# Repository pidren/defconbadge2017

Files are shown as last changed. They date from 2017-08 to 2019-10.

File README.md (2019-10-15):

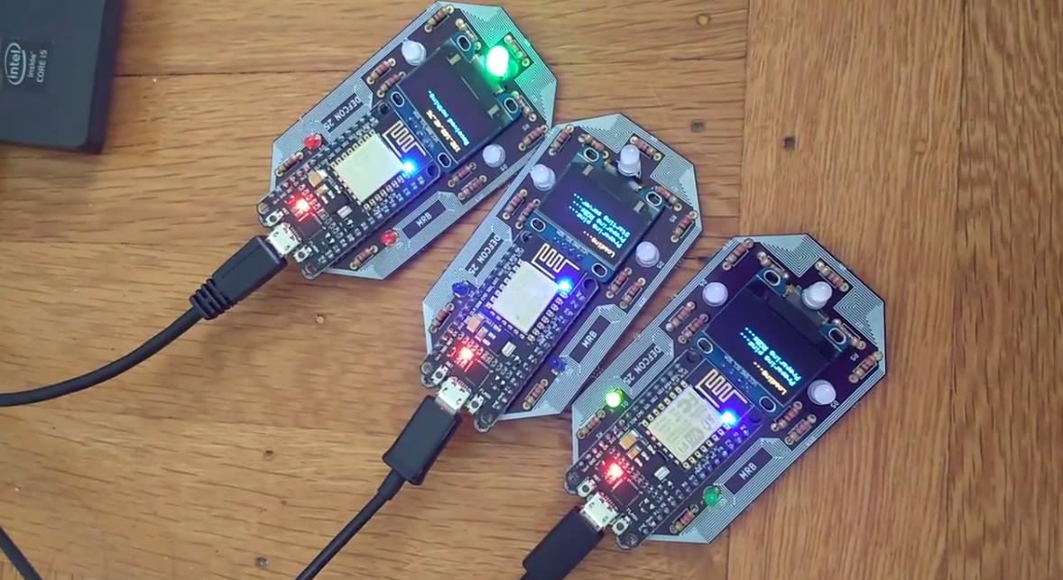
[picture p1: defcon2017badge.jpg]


# DEFCON 25 Custom Badge
Custom PCB design and code for DefCon 25 badge.
Credits to @mschuldt for help with the PCB design.

## Demo Video
[Link to Demo Video](https://www.youtube.com/watch?v=TrFcW3AFYnM)

## Why was this built?
For fun. Also I just wanted to learn how to do something I don't know how to do. At all.

## Designing the Custom PCB
Coming up with the final design took about 5 months of continuous redesigning and prototyping.
It also took a long time mostly because I didn't know anything about EE before this project. :)
The main goals of the PCB was that we would be able to fit all the components desired within
the smallest surface area possible, while also looking pleasant and something you'd want to
wear around your neck.

## What does it do?
- Each individual badge will connect to (unfortunately) hardcoded WiFi network.
- Once connected to a WiFi network, the badges will try to find their "sibling" badges by broadcasting itself on the network.
- A badge will never learn a sibling badge twice, but will try to find as many nearby siblings as possible.
- When a badge knows of at least one sibling in nearby viscinity it will start communicating.
- All badges will communicate to each other independently, and all badges will communicate to all other badges that is learned.

## Required Components for Assembly (per badge)
- Custom PCB printed by fab of your choice
  - For this badge, I used [Oshpark](https://oshpark.com/)
  - `vers2_cheaper.kicad_pcb` is the KiCAD file you can upload.
- [SSD1306 OLED Screen](https://www.amazon.com/gp/your-account/order-history?ie=UTF8&ref_=ya_d_c_yo&)
- [ESP8266 NodeMCU](https://www.amazon.com/gp/product/B010O1G1ES/ref=oh_aui_detailpage_o07_s00?ie=UTF8&psc=1)
- 220 Ohm resistors x 11
- RGB LED x 3
- 3mm LED x 2
- [3.7v 500mAh LiPo battery](https://www.adafruit.com/product/1578)
- Male microUSB connector, part only

## How to Assemble
- Basically solder on all the parts.
- Flash ESP with the arduino code using Arduino IDE version 1.6.4 and above
  - To compile correctly, you must have these libraries installed:
    - Adafruit_GFX_Library
    - Adafruit_SSD1306 Library 
    - Use board manager to install ESP modules. You'll be using the NodeMCU 1.0 ESP 12E board module.
  - You must flash in NodeMCU 1.0 ESP 12E mode. This mode has all the settings you need for the board so you should not have to touch anything.
- The battery does need manual assembly:
  - Clip off the JST end off of the LiPoly battery and solder onto the male microUSB part. 

## Useful Links
- [Pin mapping woes when addressing NodeMCU ESP GPIO pins in Arduino](https://github.com/esp8266/Arduino/issues/584)
- [If you accidentally "brick" your ESP and need to undo the damage](https://github.com/espressif/esptool/issues/213)
- [How to best work with SSD1306](http://arduino-er.blogspot.com/2016/04/nodemcu-esp8266-to-display-on-128x64.html)

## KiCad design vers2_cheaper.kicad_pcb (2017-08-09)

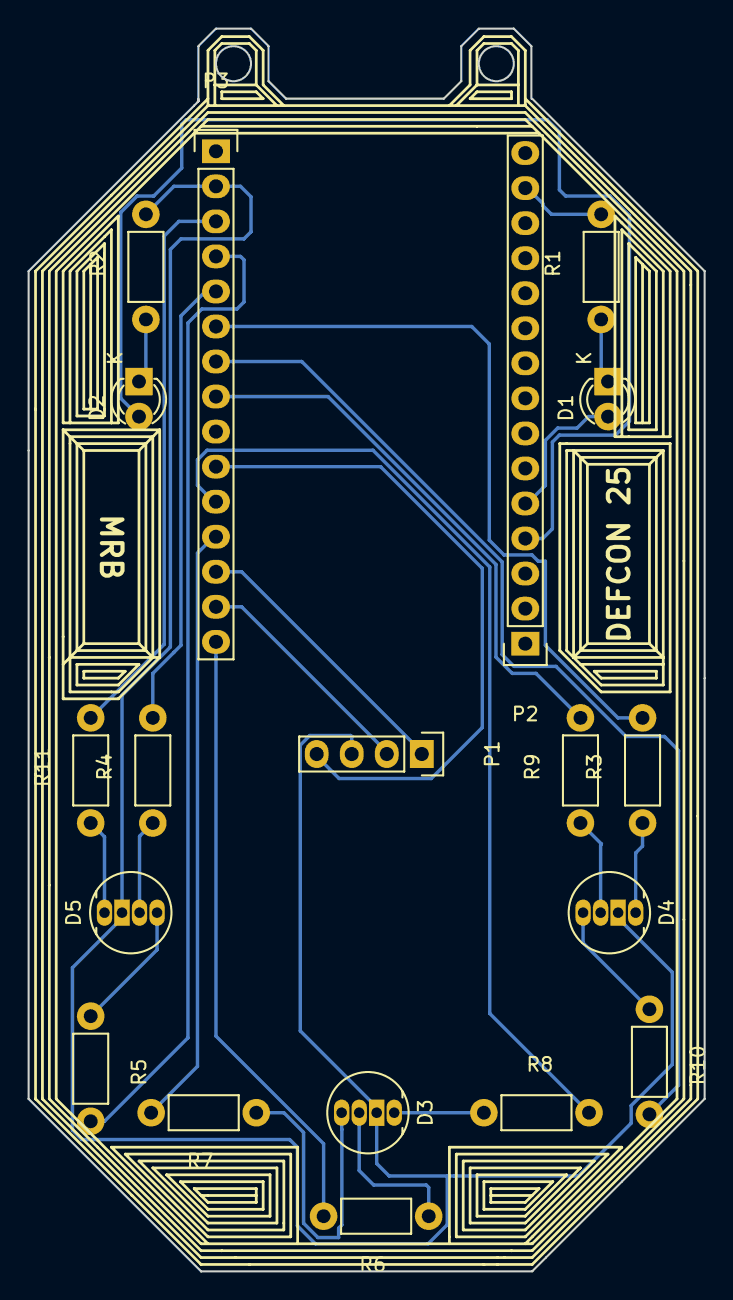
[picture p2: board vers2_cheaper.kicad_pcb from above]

Board: 2 copper layers, 49.0 x 90.1 mm, 19 parts (0 on the bottom side), 28 nets.

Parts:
D1, D2: LED; LED-3MM
D3, D4, D5: LED_RCBG; LED-RGB-5MM_Common_Cathode
P1: CONN_01X4; Pin_Header_Straight_1x04
P2, P3: CONN_01X15; Pin_Header_Straight_1x15
R1, R2, R3, R4, R5, R6, R7, R8, R9, R10, R11: 10k; Resistor_Horizontal_RM7mm

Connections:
3_3v: P1.4, P3.10
GND_2: D3.2, D4.2, D5.2, P1.3, P3.2, R2.2
GND_14: P2.14, R1.2
unnamed: D1.1, R1.1
unnamed: D2.1, R2.1
unnamed: D3.1, R8.1
unnamed: D3.3, R6.1
unnamed: D3.4, R7.1
unnamed: D4.1, R3.1
unnamed: D4.3, R9.1
unnamed: D4.4, R10.1
unnamed: D5.1, R11.1
unnamed: D5.3, R4.1
unnamed: D5.4, R5.1
d0: P3.15, R6.2
d1: P1.2, P3.14
d2: P1.1, P3.13
d3: P3.12, R7.2
d4: P3.11, R8.2
d5: P3.8, R9.2
d6: P3.7, R10.2
d7: P3.6, R3.2
d8: P3.5, R4.2
rsv: P2.2, P2.3
rx: P3.4, R5.2
sd2: D1.2, P2.5
sd3: D2.2, P2.4
tx: P3.3, R11.2

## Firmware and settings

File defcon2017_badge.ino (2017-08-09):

#include <SPI.h>
#include <Wire.h>
#include <Adafruit_GFX.h>
#include <Adafruit_SSD1306.h>
#include <ESP8266WiFi.h>
#include <WiFiUdp.h>

//--------------------------------------------------------------------------------
// ---------------------------------- SCREEN -------------------------------------
//--------------------------------------------------------------------------------
#define LOGO16_GLCD_HEIGHT 16 
#define LOGO16_GLCD_WIDTH  16 
#define OLED_RESET LED_BUILTIN //4
Adafruit_SSD1306 display(OLED_RESET);


//--------------------------------------------------------------------------------
// ------------------------------ PIN MAPPINGS -----------------------------------
//--------------------------------------------------------------------------------
#define BUILTIN_LED 16 // G of BOTTOM_MID_RGB
#define D0  16         // G of BOTTOM_MID_RGB
#define D1  5          // screen - DO NOT USE!!! Already handled by library.
#define D2  4          // screen - DO NOT USE!!! Already handled by library.
#define D3  0          // B of BOTTOM_MID_RGB
#define D4  2          // R of BOTTOM_MID_RGB, 
#define D5  14         // G of BOTTOM_RIGHT_RGB
#define D6  12         // B of BOTTOM_RIGHT_RGB
#define D7  13         // R of BOTTOM_RIGHT_RGB
#define D8  15         // G of BOTTOM_LEFT_RGB
#define D9  3          // B of BOTTOM_LEFT_RGB
#define D10 1          // R of BOTTOM_LEFT_RGB
#define TL  10         // TOPLEFT LED -- this is also SDD3
#define TR  9          // TOPRIGHT LED -- tihs is also SDD2

//RGB grouping per RGB LED in R, G, B order
uint8_t BOT_MD_RGB[] = {D4,D0,D3};
uint8_t BOT_RT_RGB[] = {D7,D5,D6};
uint8_t BOT_LT_RGB[] = {D10,D8,D9};

//R, G, B constants for easy access.
#define R 0
#define G 1
#define B 2


//--------------------------------------------------------------------------------
//---------------------------- EXPECTED BADGE ID ---------------------------------
//--------------------------------------------------------------------------------
String macIDs[6] = { "A0:20:A6:16:01:62",
                     "A0:20:A6:17:50:6A",
                     "A0:20:A6:1B:B2:DC",
                     "A0:20:A6:16:D1:7D",
                     "A0:20:A6:17:4D:1F",
                     "A0:20:A6:17:47:91" };
String ID;
void getMyID(void){
  for(int i=0; i<(sizeof(macIDs)/sizeof(String));i++){
    if(macIDs[i].equals(String(WiFi.macAddress()))){
      ID = "MRB" + String(i);
    } 
  }
}


//--------------------------------------------------------------------------------
//---------------------------- ANIMATION HELPERS ---------------------------------
//--------------------------------------------------------------------------------
#define START_X 0
#define START_STATUS_Y 0
#define START_TEXT_Y 18

void writeStatus(String s1, String s2="", String s3="", String s4="", String s5=""){
  display.clearDisplay();
  display.setTextSize(1);
  display.setTextColor(WHITE);
  display.setCursor(START_X,START_STATUS_Y);
  display.println(WiFi.localIP());
  display.println(WiFi.macAddress());
  display.setCursor(START_X,START_TEXT_Y);
  display.println(s1);
  display.println(s2);
  display.println(s3);
  display.println(s4);
  display.println(s5);
  display.display();
  delay(500);
}

void setupRGBs(void){
  setRGB(BOT_MD_RGB, 0, 0, 0);
  setRGB(BOT_LT_RGB, 0, 0, 0);
  setRGB(BOT_RT_RGB, 0, 0, 0);
}

void setRGB(uint8_t* rgb, uint8_t r_chan, uint8_t g_chan, uint8_t b_chan){
  //Set RGB channels for the RGB LEDs
  analogWrite(rgb[R], r_chan);
  analogWrite(rgb[G], g_chan);
  analogWrite(rgb[B], b_chan);
}

void setLED(uint8_t led, uint8_t v){
  analogWrite(led, v);
}

void rainbowRGB(uint8_t* rgb){
  //Tries to simulate rainbow for all RGB LEDs
  //Red(255,0,0) --> Green(0,255,0) --> Blue(0,0,255)
  setRGB(rgb,255,0,0);
  delay(300);
  for(int i=255; i>=0; i--){
    setRGB(rgb, i, abs(i-255), 0);
    delay(2);
  }
  for(int i=255; i>=0; i--){
    setRGB(rgb,0, i, abs(i-255));
    delay(2); 
  }    
}

void rainbowAllRGB(void){
  setRGB(BOT_LT_RGB,255,0,0);
  setRGB(BOT_RT_RGB,255,0,0);
  setRGB(BOT_MD_RGB,255,0,0);
  delay(300);
  for(int i=255; i>=0; i--){
    setRGB(BOT_LT_RGB, i, abs(i-255), 0);
    setRGB(BOT_RT_RGB, i, abs(i-255), 0);
    setRGB(BOT_MD_RGB, i, abs(i-255), 0);
    delay(2);
  }
  for(int i=255; i>=0; i--){
    setRGB(BOT_LT_RGB, 0, i, abs(i-255));
    setRGB(BOT_RT_RGB, 0, i, abs(i-255));
    setRGB(BOT_MD_RGB, 0, i, abs(i-255));
    delay(2); 
  }   
}


void flickerLED(uint8_t led){
  //Quick flicker animation for LED, best used for visual status
  digitalWrite(led, HIGH);
  delay(10);
  digitalWrite(led, LOW);
}

//--------------------------------------------------------------------------------
//---------------------------- WIFI SERVER HELPERS -------------------------------
//--------------------------------------------------------------------------------
#define PORT 80
WiFiUDP node;
//I only printed 6 of these so there should be 5 other siblings at most...
IPAddress siblings[5];

void printWifiStat(int s){
  switch(s){
    case WL_CONNECTED:
      Serial.println( "CONNECTED" );
      break;
    case WL_NO_SHIELD:
      Serial.println( "NO SHIELD" ); 
      break;
    case WL_IDLE_STATUS:
      Serial.println( "Idle" );
      break;
    case WL_NO_SSID_AVAIL:
      Serial.println( "NO SSID" ); 
      break;
    case WL_SCAN_COMPLETED:
      Serial.println( "NETWORK SCAN COMPLETE" );  
      break; 
    case WL_CONNECT_FAILED:
      Serial.println( "FAILED" ); 
      break;
    case WL_CONNECTION_LOST:
      Serial.println( "Connection lost" );
      break;
    case WL_DISCONNECTED:
      Serial.println( "DISCONNECTED " );
      break; 
  }
}

void setupNode(void){
  WiFi.hostname(ID);
  WiFi.begin("Unicorn","stankybutt");
  while(WiFi.status() != WL_CONNECTED){
    flickerLED(TL);
    delay(250);
    flickerLED(TR);
    printWifiStat(WiFi.status());
    delay(250);
  }  
  node.begin(PORT);
} 

boolean missingSiblings(){
  for(int i=0; i < (sizeof(siblings)/sizeof(IPAddress)); i++){
    if(siblings[i] == IPAddress(0,0,0,0)){
      return true; 
    }    
  }
  return false;
}

boolean addSibling(IPAddress newsib){
  for(int i=0; i < (sizeof(siblings)/sizeof(IPAddress)); i++){
    if(siblings[i] == newsib){
      //If there is a duplicate, early exit
      return false; 
    }
    
    if(siblings[i] == IPAddress(0,0,0,0)){
      //If new sibling added, early exit
      siblings[i] = newsib;
      return true; 
    }
  }
  return false;
}

int numSiblings(void){
  int i=0;
  for(; i < (sizeof(siblings)/sizeof(IPAddress)); i++){
    if(siblings[i] == IPAddress(0,0,0,0)){
      return i;
    }    
  }
  return i;
}


void respond(void){
  writeStatus("Listening...");
  flickerLED(TL);
  delay(200);
  flickerLED(TR);
  delay(200);
  
  //If can add more siblings, try to broadcast yourself
  if(missingSiblings()) {
    IPAddress broadcastIP = WiFi.localIP();
    broadcastIP[3] = 255; //turn last octal to broadcast
    char buf[] = "BROADCAST";
    node.beginPacket(broadcastIP, PORT);
    node.write(buf);
    node.endPacket();
  }
  
  int pkt = node.parsePacket();
  //Make sure we ignore packets that came from the badge itself
  if(pkt && (node.remoteIP() != WiFi.localIP())){
    //Received something!
    flickerLED(TL);
    flickerLED(TR);
     
    //Read in the packet payload and null terminate the end.
    char pktBuf[255];
    int len = node.read(pktBuf,255);
    if (len > 0) {
      pktBuf[len] = 0; 
    }
    
    //If payload contains "BROADCAST" message, try to add the new sibling to list of siblings
    if(String(pktBuf) == "BROADCAST"){
      if(addSibling(node.remoteIP())){
        writeStatus("Added new sibling: " + node.remoteIP().toString()); 
        setRGB(BOT_LT_RGB, 0, 255, 0);
        setRGB(BOT_RT_RGB, 0, 255, 0);
        setRGB(BOT_MD_RGB, 0, 255, 0);
        delay(200);
      } else {
        writeStatus("Didn't add sibling: " + node.remoteIP().toString());
        setRGB(BOT_LT_RGB, 255, 0, 0);
        setRGB(BOT_RT_RGB, 255, 0, 0);
        setRGB(BOT_MD_RGB, 255, 0, 0);
        delay(200);
      }
      writeStatus("Number of Siblings: " + String(numSiblings()));
      delay(200);
    } else {
      rainbowAllRGB();
      writeStatus("Received: " + String(pktBuf), "From: " + node.remoteIP().toString());
      delay(200);
    }
      
    //Reply with a simple hello!
    String msg = "Hello from " + WiFi.localIP().toString();
    char replyBuf[msg.length()+1];
    msg.toCharArray(replyBuf,msg.length()+1);
    node.beginPacket(node.remoteIP(), PORT);
    node.write(replyBuf);
    node.endPacket();
    
    //Let's say hello to any other siblings we already have
    writeStatus("Saying hi to all siblings");
    for(int i=0; i<(sizeof(siblings)/sizeof(IPAddress)); i++){
      node.beginPacket(siblings[i], PORT);
      node.write(replyBuf);
      node.endPacket();
    }
  } else {
    //Didn't receive a packet.
    writeStatus("Received nothing.");
  }
}


//--------------------------------------------------------------------------------
//----------------------------------- SETUP --------------------------------------
//--------------------------------------------------------------------------------
void setup()   {  
  delay(500);
  // Set baud rate to 115200 for Serial Logs
  Serial.begin(115200);
  
  //Clear siblings IPAddress list
  memset(siblings, 0, sizeof(siblings));
  
  // Generate the high voltage from the 3.3v line internally
  // Initialize with the I2C addr 0x3D (for the 128x64)
  display.begin(SSD1306_SWITCHCAPVCC, 0x3C);  
  
  //Instead of writing to Serial we'll show loading messages on screen.
  //Keeping showing loading screen until ready
  display.clearDisplay();
  display.setTextSize(1);
  display.setTextColor(WHITE);
  display.setCursor(0,0);
  display.println("Loading...");
  display.display();
  
  // Initialize Pins (note: putting this in a loop does not work.)
  display.setCursor(0,16);
  display.println("Preparing pins...");
  display.display();
  pinMode(BOT_MD_RGB[R],OUTPUT);
  pinMode(BOT_MD_RGB[G],OUTPUT);
  pinMode(BOT_MD_RGB[B],OUTPUT);
  pinMode(BOT_LT_RGB[R],OUTPUT); // This pin is screwing up serial messages --- BYPASS BY WRITING TO SCREEN
  pinMode(BOT_LT_RGB[G],OUTPUT);
  pinMode(BOT_LT_RGB[B],OUTPUT);
  pinMode(BOT_RT_RGB[R],OUTPUT);
  pinMode(BOT_RT_RGB[G],OUTPUT);
  pinMode(BOT_RT_RGB[B],OUTPUT);
  pinMode(TL,OUTPUT);
  //pinMode(TR,OUTPUT); // This needs to be commented out for green board
  delay(500);
  
  //Initialize RGB LED
  display.setCursor(0,26);
  display.println("Preparing RGBs...");
  display.display();
  setupRGBs();
  delay(800);

  //Setup Server
  display.setCursor(0,36);
  display.print("Starting server...");
  display.display();
  setupNode();  
  display.setCursor(0,46);
  display.println("Done.");
  display.display();
  delay(800);
}


//--------------------------------------------------------------------------------
//--------------------------------- MAIN LOOP ------------------------------------
//--------------------------------------------------------------------------------
void loop() { 
  respond();
  delay(200);
}

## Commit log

2017-07-04 This is initial commit containing the correct ping mapping for all the RGBs and top LEDs.
    [defcon2017_badge.ino]
2017-07-04 Corrected pin mappings and setup a test
    [defcon2017_badge.ino]
2017-07-12 Lots of library functions added 1. RGB color channel controls, rainbow function 2. LED controls, flicker 3. Starting loading/banner done 4. Wrote notes in sections where Wifi Server setup should go.
2017-07-17 Cleaned up unnecessary code; changed HTTP server to UDP server; While connecting to WiFi LEDs flicker
2017-07-20 Fixed the issue with addressing and addressing siblings
    [defcon2017_badge.ino]
2017-08-09 Updating README
    [vers2_cheaper.kicad_pcb]
